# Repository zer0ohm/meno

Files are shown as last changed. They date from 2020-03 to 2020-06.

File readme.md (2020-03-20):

# meno
試作中のArduino互換機 (無保証)

## Meno
マイコンにATmega2560、USBコネクタにType-Cを採用したボードです。 GPIOは公式のMEGAと同じ70本です。(内訳: ディジタルI/O 54本、アナログI/O 16本)
* 回路図: [Meno_sch.pdf](https://github.com/zer0ohm/meno/blob/master/Meno/Schematic/Meno_sch.pdf)
* 部品表: [Meno_BOM.pdf](https://github.com/zer0ohm/meno/blob/master/Meno/Docs/Meno_BOM.pdf) もしくは [Meno_BOM.md](https://github.com/zer0ohm/meno/blob/master/Meno/Docs/Meno_BOM.md)
* 組み立て方法: [Meno_assemble.md](https://github.com/zer0ohm/meno/blob/master/Meno/Docs/Meno_assemble.md)

<!--// まだ構想中なのでとりあえずコメントアウト
## Meno F4
MenoのマイコンをSTM32F4(STM32F446RET)にアップグレードしたボードです。USBコネクタは引き続きType-Cを採用しています。
* 回路図: [MenoF4_RevPrototype_sch.pdf](https://github.com/zer0ohm/meno/blob/master/MenoF4/Schematic/MenoF4_RevPrototype_sch.pdf)
* 部品表: [MenoF4_BOM.pdf](https://github.com/zer0ohm/meno/blob/master/MenoF4/Docs/MenoF4_BOM.pdf) もしくは [MenoF4_BOM.md](https://github.com/zer0ohm/meno/blob/master/MenoF4/Docs/MenoF4_BOM.md)
* 組み立て方法: [MenoF4_assemble.md](https://github.com/zer0ohm/meno/blob/master/MenoF4/Docs/Meno_assemble.md)
-->

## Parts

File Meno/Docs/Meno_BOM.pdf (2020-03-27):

基板上部品番号 | 個数 | 製品名や各種定数 | 製品型番 | 製造社名 | 部品概要
C1, 2, 3, 4, 5, 8, 9, 11, 14 | 9 | 0.1u | GRM219F11H104ZA01D | Murata Electronics | チップコンデンサ (*1)
C6, 7 | 2 | 22p | GRM21A5C2D220JW01D | Murata Electronics | チップコンデンサ
C10 | 1 | 0.22u | GCM21BR71H224KA37K | Murata Electronics | チップコンデンサ
C12, 13, 15 | 3 | 1u | GRM21BC72A105KE01 | Murata Electronics | チップコンデンサ
D1 | 1 | L | PG1112H-TR (*2) | STANLEY ELECTRIC | Lチカ用LED
D2 | 1 | TX | PG1112H-TR (*2) | STANLEY ELECTRIC | シリアル通信時インジケータ用LED
D3 | 1 | RX | PG1112H-TR (*2) | STANLEY ELECTRIC | シリアル通信時インジケータ用LED
D4 | 1 | ON | PG1112H-TR (*2) | STANLEY ELECTRIC | 電源投入インジケータ用LED
D5 | 1 | 1N4148W | 1N4148W-7-F | Diodes Incorporated | 汎用ダイオード
D6, 7 | 2 | RB160MM-30 | RB160MM-30TR | Rohm Semiconductor | ショットキーダイオード
F1 | 1 | MF-MSMF050-2 | MF-MSMF050-2 | Bourns | リセッタブルヒューズ (Ih=500[mA], It=1[A])
J1 | 1 | 5077CR-16SMC2 | 5077CR-16SMC2-BK-TR | Neltron Industrial | USB3.1 Type-C型コネクタ
J2 | 1 | AVR-ISP-6 | PH-2x7SG | Useconn Electronics | AVR ICSP用ピンヘッダ
J3 | 1 | 18742 | 18742 | 4UCON | DCジャック (20[V], 4[A]絶対定格)
J4, 5, 6 | 3 | Conn_01x08, 10, 19 | FHU-1x42SG | Useconn Electronics | GPIO用ピンソケット (*3)
J7, 8, 9 | 3 | Conn_01x06, 08, 15 | FHU-1x42SG | Useconn Electronics | GPIO用ピンソケット (*3)
J10 | 1 | Conn_02x12 | FHU-2x42SG | Useconn Electronics | GPIO用ピンソケット
L1 | 1 | MH2029-300Y | MH2029-300Y | Bourns | フェライトビーズ
Q1 | 1 | IRLML6402 | IRLML6402TRPBF | International Rectifier | Pch型MOSFET
R1, 2, 3 | 3 | 10k | RK73B2ATTD103J | KOA | チップ抵抗 (0.25W)
R4, 5, 6, 7 | 4 | 1k | RK73B2ATTD102J | KOA | チップ抵抗 (0.25W)
R8, 9 | 2 | 5.1k | RK73B2ATTD512J | KOA | チップ抵抗 (0.25W)
R10 | 1 | 33k | RK73B2ATTD333J | KOA | チップ抵抗 (0.25W)
SW1 | 1 | B3FS-1050P | B3FS-1050P | Omron Electronics | タクトスイッチ
U1 | 1 | ATmega2560-16AUR | ATmega2560-16AUR | Atmel/Microchip | マイコン
U2 | 1 | FT232RL | FT232RL-REEL | FTDI | USB/シリアル変換IC
U3 | 1 | LM340MPX-5.0/NOPB | LM340MPX-5.0/NOPB | Texas Instruments | 5Vレギュレータ (1.5[A]絶対定格)
U4 | 1 | TLV75733PDBVR | TLV75733PDBVR | Texas Instruments | 3.3Vレギュレータ (1.0[A]絶対定格)
Y1 | 1 | FA238-16MHz | FA-238 16.0000MB-K3 | EPSON | 水晶振動子

*3: ピンソケットの外側のピン配置はArduino Unoと互換。 Meno-PinMapping.pngを参照。

*2: ロットによってはOpto Supply製のOSG80805C1Cの場合あり。 もしくは同等品 (参考: 条件= IF=20[mA](typ), VF=2.1[V](typ), 2012Metric)。

*1: 既にディスコン(製造中止)しているため、次回以降の生産時は同社製の代替品に切替予定 (参考: 条件=0.1uF, 50V, X7R, 2012Metric)。

Meno BOM v1.0-20200327 1頁目/3頁

Meno BOM v1.0-20200327 2頁目/3頁

基板上部品番号 | 個数 | フットプリント - 特記なしはKiCadでの名称 | Digikey通販コード | 秋月通販コード
C1, 2, 3, 4, 5, 8, 9, 11, 14 | 9 | Capacitor_SMD:C_0805_2012Metric_Pad1.15x1.40mm_HandSolder N/A | | P-13372 (50個/袋)
C6, 7 | 2 | Capacitor_SMD:C_0805_2012Metric_Pad1.15x1.41mm_HandSolder 490-14650-1-ND | | N/A
C10 | 1 | Capacitor_SMD:C_0805_2012Metric_Pad1.15x1.42mm_HandSolder 490-13311-1-ND | | N/A
C12, 13, 15 | 3 | Capacitor_SMD:C_0805_2012Metric_Pad1.15x1.43mm_HandSolder 490-14464-1-ND | | P-13699 (10個/袋)
D1 | 1 | LED_SMD:LED_0805_2012Metric_Pad1.15x1.40mm_HandSolder | 404-1021-1-ND | I-09340 (20個/袋)
D2 | 1 | LED_SMD:LED_0805_2012Metric_Pad1.15x1.41mm_HandSolder | D1に同じ | D1に同じ
D3 | 1 | LED_SMD:LED_0805_2012Metric_Pad1.15x1.42mm_HandSolder | D1に同じ | D1に同じ
D4 | 1 | LED_SMD:LED_0805_2012Metric_Pad1.15x1.43mm_HandSolder | D1に同じ | D1に同じ
D5 | 1 | SOD123(F)-HandSolder:D_SOD-123 | 1N4148W-FDICT-ND | I-07084 (40個/袋)
D6, 7 | 2 | SOD123(F)-HandSolder:D_SOD-123 | RB160MM-30CT-ND | I-01398 (10個/袋)
F1 | 1 | Fuse:Fuse_1812_4532Metric_Pad1.30x3.40mm_HandSolder | MF-MSMF050-2CT-ND | N/A
J1 | 1 | 5077CR-16SMC2-BK-TR:GCT_USB4105-GF-A (gct.coから) | 2073-USB4105-GF-ACT-ND | C-14356
J2 | 1 | Connector_PinHeader_2.54mm:PinHeader_2x03_P2.54mm_Vertical N/A | | C-00166
J3 | 1 | CUI_PJ-102A:CUI_PJ-102A (cuidevices.comから) | CP-102A-ND | C-09408
J4, 5, 6 | 3 | Connector_PinSocket_2.54mm:PinSocket_1x08, 10, 19 | N/A | C-05779
J7, 8, 9 | 3 | Connector_PinSocket_2.54mm:PinSocket_1x06, 08, 15 | J4, 5, 6に同じ | J4, 5, 6に同じ
J10 | 1 | Connector_PinSocket_2.54mm:PinSocket_2x12 | J4, 5, 6に同じ | C-05780
L1 | 1 | Inductor_SMD:L_0805_2012Metric_Pad1.15x1.40mm_HandSolder | MH2029-300YCT-ND | N/A
Q1 | 1 | Package_TO_SOT_SMD:SOT-23_Handsoldering | IRLML6402PBFCT-ND | I-02553 (10個/袋)
R1, 2, 3 | 3 | Resistor_SMD:R_0805_2012Metric_Pad1.15x1.40mm_HandSolder | 2019-RK73B2ATTD102JCT-ND | N/A
R4, 5, 6, 7 | 4 | Resistor_SMD:R_0805_2012Metric_Pad1.15x1.41mm_HandSolder | 2019-RK73B2ATTD103JCT-ND | N/A
R8, 9 | 2 | Resistor_SMD:R_0805_2012Metric_Pad1.15x1.42mm_HandSolder | 2019-RK73B2ATTD512JCT-ND | N/A
R10 | 1 | Resistor_SMD:R_0805_2012Metric_Pad1.15x1.43mm_HandSolder | 2019-RK73B2ATTD333JCT-ND | N/A
SW1 | 1 | B3FS-1050P:B3FS-1012 (ultralibrarian.comから) | Z5350CT-ND | P-10527
U1 | 1 | Package_QFP:TQFP-100_14x14mm_P0.5mm | ATMEGA2560-16AURCT-ND | N/A
U2 | 1 | Package_SO:SSOP-28_5.3x10.2mm_P0.65mm | 768-1007-1-ND | I-01739
U3 | 1 | Package_TO_SOT_SMD:SOT-223-3_TabPin2 | LM340MPX-5.0/NOPBCT-ND | N/A
U4 | 1 | Package_TO_SOT_SMD:SOT-23-5_HandSoldering | 296-50414-1-ND | N/A
Y1 | 1 | Crystal:Crystal_SMD_SeikoEpson_FA238-4Pin_3.2x2.5mm_HandSoldering | SER4046CT-ND | P-02457 (4個/袋)

基板上部品番号 | 個数 | データシート - もしくは関連資料
C1, 2, 3, 4, 5, 8, 9, 11, 14 | 9 | http://akizukidenshi.com/download/ds/murata/grm219f11h104za01.pdf
C6, 7 | 2 | https://psearch.jp.murata.com/capacitor/product/GRM21A5C2D220JW01%23.html
C10 | 1 | https://psearch.jp.murata.com/capacitor/product/GCM21BR71H224KA37%23.html
C12, 13, 15 | 3 | https://psearch.jp.murata.com/capacitor/product/GRM21BC72A105KE01%23.html
D1 | 1 | https://media.digikey.com/pdf/Data%20Sheets/Stanley%20Electric%20PDFs/BR1112H.pdf
D2 | 1
D3 | 1
D4 | 1
D5 | 1 | https://www.diodes.com/assets/Datasheets/ds30086.pdf
D6, 7 | 2 | https://fscdn.rohm.com/jp/products/databook/datasheet/discrete/diode/schottky_barrier/rb160mm-30tr-j.pdf
F1 | 1 | https://www.bourns.com/docs/Product-Datasheets/mfmsmf.pdf
J1 | 1 | https://www.amphenol-icc.com/media/wysiwyg/files/drawing/12401610e4x2a.pdf
J2 | 1 | http://akizukidenshi.com/download/ds/useconn/PH-2xXXSG-AD.pdf
J3 | 1 | https://www.cuidevices.com/product/resource/pj-102a.pdf
J4, 5, 6 | 3
J7, 8, 9 | 3
J10 | 1 | http://akizukidenshi.com/download/ds/useconn/FHU-2xXXSG-AD.pdf
L1 | 1 | https://www.bourns.com/docs/Product-Datasheets/mh.pdf
Q1 | 1 | https://www.infineon.com/dgdl/irlml6402pbf.pdf?fileId=5546d462533600a401535668d5c2263c
R1, 2, 3 | 3 | https://www.koaglobal.com/-/media/Files/KOA_Global/product/commonpdf/rk73b.pdf
R4, 5, 6, 7 | 4
R8, 9 | 2
R10 | 1
SW1 | 1 | https://omronfs.omron.com/ja_JP/ecb/products/pdf/b3fs.pdf
U1 | 1 | https://ww1.microchip.com/downloads/en/DeviceDoc/Atmel-2549-8-bit-AVR-Microcontroller-ATmega640-1280-1281-2560-2561_datasheet.pdf (https://ww1.microchip.com/downloads/en/DeviceDoc/Atmel-2549-8-bit-AVR-Microcontroller-ATmega640-1280-1281-2560-2561_datasheet.pdf)
U2 | 1 | https://www.ftdichip.com/Products/ICs/FT232RL.htm
U3 | 1 | https://www.ti.com/lit/ds/symlink/lm340.pdf
U4 | 1 | https://www.ti.com/lit/ds/symlink/tlv757p.pdf
Y1 | 1 | https://support.epson.biz/td/api/doc_check.php?dl=brief_FA-238&lang=ja

Meno BOM v1.0-20200327 3頁目/3頁

http://akizukidenshi.com/download/ds/useconn/FHU-1.pdf

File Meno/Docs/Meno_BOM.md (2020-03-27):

# Meno BOM v1.0-20200327
 * 印刷用データはMeno_BOM.pdfをご利用ください。

## 1ページ目 (部品名や概要等)

| 基板上部品番号 | 個数 | 製品名や各種定数  | 製品型番 | 製造社名 | 部品概要 |
|---|---|---|---|---|---|
| C1, 2, 3, 4, 5, 8, 9, 11, 14 | 9 | 0.1u | GRM219F11H104ZA01D  | Murata Electronics | チップコンデンサ (*1) |
| C6, 7 | 2 | 22p | GRM21A5C2D220JW01D  | Murata Electronics | チップコンデンサ |
| C10 | 1 | 0.22u | GCM21BR71H224KA37K  | Murata Electronics | チップコンデンサ |
| C12, 13, 15 | 3 | 1u | GRM21BC72A105KE01 | Murata Electronics | チップコンデンサ |
| D1 | 1 | L | PG1112H-TR (*2) | STANLEY ELECTRIC | Lチカ用LED |
| D2 | 1 | TX | PG1112H-TR (*2) | STANLEY ELECTRIC | シリアル通信時インジケータ用LED |
| D3 | 1 | RX | PG1112H-TR (*2) | STANLEY ELECTRIC | シリアル通信時インジケータ用LED |
| D4 | 1 | ON | PG1112H-TR (*2) | STANLEY ELECTRIC | 電源投入インジケータ用LED |
| D5 | 1 | 1N4148W | 1N4148W-7-F | Diodes Incorporated | 汎用ダイオード |
| D6, 7 | 2 | RB160MM-30 | RB160MM-30TR | Rohm Semiconductor | ショットキーダイオード |
| F1 | 1 | MF-MSMF050-2 | MF-MSMF050-2 | Bourns | リセッタブルヒューズ (Ih=500[mA], It=1[A]) |
| J1 | 1 | 5077CR-16SMC2 | 5077CR-16SMC2-BK-TR | Neltron Industrial | USB3.1 Type-C型コネクタ |
| J2 | 1 | AVR-ISP-6 | PH-2x7SG | Useconn Electronics | AVR ICSP用ピンヘッダ |
| J3 | 1 | 18742 | 18742 | 4UCON | DCジャック (20[V], 4[A]絶対定格) |
| J4, 5, 6 | 3 | Conn_01x08, 10, 19 | FHU-1x42SG | Useconn Electronics | GPIO用ピンソケット (*3) |
| J7, 8, 9 | 3 | Conn_01x06, 08, 15 | FHU-1x42SG | Useconn Electronics | GPIO用ピンソケット (*3) |
| J10 | 1 | Conn_02x12 | FHU-2x42SG | Useconn Electronics | GPIO用ピンソケット |
| L1 | 1 | MH2029-300Y | MH2029-300Y | Bourns | フェライトビーズ |
| Q1 | 1 | IRLML6402 | IRLML6402TRPBF | International Rectifier | Pch型MOSFET |
| R1, 2, 3 | 3 | 10k | RK73B2ATTD103J | KOA | チップ抵抗 (0.25W) |
| R4, 5, 6, 7 | 4 | 1k | RK73B2ATTD102J | KOA | チップ抵抗 (0.25W) |
| R8, 9 | 2 | 5.1k | RK73B2ATTD512J | KOA | チップ抵抗 (0.25W) |
| R10 | 1 | 33k | RK73B2ATTD333J | KOA | チップ抵抗 (0.25W) |
| SW1 | 1 | B3FS-1050P | B3FS-1050P | Omron Electronics | タクトスイッチ |
| U1 | 1 | ATmega2560-16AUR  | ATmega2560-16AUR | Atmel/Microchip | マイコン |
| U2 | 1 | FT232RL | FT232RL-REEL | FTDI | USB/シリアル変換IC |
| U3 | 1 | LM340MPX-5.0/NOPB | LM340MPX-5.0/NOPB | Texas Instruments | 5Vレギュレータ (1.5[A]絶対定格) |
| U4 | 1 | TLV75733PDBVR | TLV75733PDBVR | Texas Instruments | 3.3Vレギュレータ (1.0[A]絶対定格) |
| Y1 | 1 | FA238-16MHz | FA-238 16.0000MB-K3 | EPSON | 水晶振動子 |

### 注釈
 * &#x2a;1: 既にディスコン(製造中止)しているため、次回以降の生産時は同社製の代替品に切替予定 (参考: 条件=0.1uF, 50V, X7R, 2012Metric)。
 * &#x2a;2: ロットによってはOpto Supply製のOSG80805C1Cの場合あり。 もしくは同等品 (参考: 条件= IF=20[mA]&#x28;typ&#x29;, VF=2.1[V]&#x28;typ&#x29;, 2012Metric)。
 * &#x2a;3: ピンソケットの外側のピン配置はArduino Unoと互換。 Meno-PinMapping.pngを参照。

## 2ページ目 (フットプリントや通販コード)

| 基板上部品番号 | 個数 | フットプリント - 特記なしはKiCadでの名称 | Digikey通販コード | 秋月通販コード |
|---|---|---|---|---|
| C1, 2, 3, 4, 5, 8, 9, 11, 14 | 9 | Capacitor_SMD:C_0805_2012Metric_Pad1.15x1.41mm_HandSolder | N/A | P-13372 (50個/袋) |
| C6, 7 | 2 | Capacitor_SMD:C_0805_2012Metric_Pad1.15x1.41mm_HandSolder | 490-14650-1-ND | N/A |
| C10 | 1 | Capacitor_SMD:C_0805_2012Metric_Pad1.15x1.41mm_HandSolder | 490-13311-1-ND | N/A |
| C12, 13, 15 | 3 | Capacitor_SMD:C_0805_2012Metric_Pad1.15x1.41mm_HandSolder | 490-14464-1-ND | P-13699 (10個/袋) |
| D1 | 1 | LED_SMD:LED_0805_2012Metric_Pad1.15x1.40mm_HandSolder | 404-1021-1-ND | I-09340 (20個/袋) |
| D2 | 1 | LED_SMD:LED_0805_2012Metric_Pad1.15x1.40mm_HandSolder | D1に同じ | D1に同じ |
| D3 | 1 | LED_SMD:LED_0805_2012Metric_Pad1.15x1.40mm_HandSolder | D1に同じ | D1に同じ |
| D4 | 1 | LED_SMD:LED_0805_2012Metric_Pad1.15x1.40mm_HandSolder | D1に同じ | D1に同じ |
| D5 | 1 | SOD123(F)-HandSolder:D_SOD-123 | 1N4148W-FDICT-ND | I-07084 (40個/袋) |
| D6, 7 | 2 | SOD123(F)-HandSolder:D_SOD-123 | RB160MM-30CT-ND | I-01398 (10個/袋) |
| F1 | 1 | Fuse:Fuse_1812_4532Metric_Pad1.30x3.40mm_HandSolder | MF-MSMF050-2CT-ND | N/A |
| J1 | 1 | 5077CR-16SMC2-BK-TR:GCT_USB4105-GF-A (gct.coから) | 2073-USB4105-GF-ACT-ND | C-14356 |
| J2 | 1 | Connector_PinHeader_2.54mm:PinHeader_2x03_P2.54mm_Vertical | N/A | C-00166 |
| J3 | 1 | CUI_PJ-102A:CUI_PJ-102A (cuidevices.comから) | CP-102AH-ND | C-09408 |
| J4, 5, 6 | 3 | Connector_PinSocket_2.54mm:PinSocket_1x08, 10, 19 | N/A | C-05779 |
| J7, 8, 9 | 3 | Connector_PinSocket_2.54mm:PinSocket_1x06, 08, 15 | J4, 5, 6に同じ | J4, 5, 6に同じ |
| J10 | 1 | Connector_PinSocket_2.54mm:PinSocket_2x12 | J4, 5, 6に同じ | C-05780 |
| L1 | 1 | Inductor_SMD:L_0805_2012Metric_Pad1.15x1.40mm_HandSolder | MH2029-300YCT-ND | N/A |
| Q1 | 1 | Package_TO_SOT_SMD:SOT-23_Handsoldering | IRLML6402PBFCT-ND | I-02553 (10個/袋) |
| R1, 2, 3 | 3 | Resistor_SMD:R_0805_2012Metric_Pad1.15x1.41mm_HandSolder | 2019-RK73B2ATTD102JCT-ND | N/A |
| R4, 5, 6, 7 | 4 | Resistor_SMD:R_0805_2012Metric_Pad1.15x1.41mm_HandSolder | 2019-RK73B2ATTD103JCT-ND | N/A |
| R8, 9 | 2 | Resistor_SMD:R_0805_2012Metric_Pad1.15x1.41mm_HandSolder | 2019-RK73B2ATTD512JCT-ND | N/A |
| R10 | 1 | Resistor_SMD:R_0805_2012Metric_Pad1.15x1.41mm_HandSolder | 2019-RK73B2ATTD333JCT-ND | N/A |
| SW1 | 1 | B3FS-1050P:B3FS-1012 (ultralibrarian.comから) | Z5350CT-ND | P-10527 |
| U1 | 1 | Package_QFP:TQFP-100_14x14mm_P0.5mm | ATMEGA2560-16AURCT-ND | N/A |
| U2 | 1 | Package_SO:SSOP-28_5.3x10.2mm_P0.65mm | 768-1007-1-ND | I-01739 |
| U3 | 1 | Package_TO_SOT_SMD:SOT-223-3_TabPin2 | LM340MPX-5.0/NOPBCT-ND | N/A |
| U4 | 1 | Package_TO_SOT_SMD:SOT-23-5_HandSoldering | 296-50414-1-ND | N/A |
| Y1 | 1 | Crystal:Crystal_SMD_SeikoEpson_FA238-4Pin_3.2x2.5mm_HandSoldering | SER4046CT-ND | P-02457 (4個/袋)  |

## 3ページ目 (データシートや関連資料)

| 基板上部品番号 | 個数 | データシート - もしくは関連資料 |
|---|---|---|
| C1, 2, 3, 4, 5, 8, 9, 11, 14 | 9 | http://akizukidenshi.com/download/ds/murata/grm219f11h104za01.pdf |
| C6, 7 | 2 | https://psearch.jp.murata.com/capacitor/product/GRM21A5C2D220JW01%23.html |
| C10 | 1 | https://psearch.jp.murata.com/capacitor/product/GCM21BR71H224KA37%23.html |
| C12, 13, 15 | 3 | https://psearch.jp.murata.com/capacitor/product/GRM21BC72A105KE01%23.html |
| D1 | 1 | https://media.digikey.com/pdf/Data%20Sheets/Stanley%20Electric%20PDFs/BR1112H.pdf |
| D2 | 1 | https://media.digikey.com/pdf/Data%20Sheets/Stanley%20Electric%20PDFs/BR1112H.pdf |
| D3 | 1 | https://media.digikey.com/pdf/Data%20Sheets/Stanley%20Electric%20PDFs/BR1112H.pdf |
| D4 | 1 | https://media.digikey.com/pdf/Data%20Sheets/Stanley%20Electric%20PDFs/BR1112H.pdf |
| D5 | 1 | https://www.diodes.com/assets/Datasheets/ds30086.pdf |
| D6, 7 | 2 | https://fscdn.rohm.com/jp/products/databook/datasheet/discrete/diode/schottky_barrier/rb160mm-30tr-j.pdf |
| F1 | 1 | https://www.bourns.com/docs/Product-Datasheets/mfmsmf.pdf |
| J1 | 1 | https://www.amphenol-icc.com/media/wysiwyg/files/drawing/12401610e4x2a.pdf |
| J2 | 1 | http://akizukidenshi.com/download/ds/useconn/PH-2xXXSG-AD.pdf |
| J3 | 1 | https://www.cuidevices.com/product/resource/pj-102a.pdf |
| J4, 5, 6 | 1 | http://akizukidenshi.com/download/ds/useconn/FHU-1.pdf |
| J7, 8, 9 | 1 | http://akizukidenshi.com/download/ds/useconn/FHU-1.pdf |
| J10 | 1 | http://akizukidenshi.com/download/ds/useconn/FHU-2xXXSG-AD.pdf |
| L1 | 1 | https://www.bourns.com/docs/Product-Datasheets/mh.pdf |
| Q1 | 1 | https://www.infineon.com/dgdl/irlml6402pbf.pdf?fileId=5546d462533600a401535668d5c2263c |
| R1, 2, 3 | 3 | https://www.koaglobal.com/-/media/Files/KOA_Global/product/commonpdf/rk73b.pdf |
| R4, 5, 6, 7 | 4 | https://www.koaglobal.com/-/media/Files/KOA_Global/product/commonpdf/rk73b.pdf |
| R8, 9 | 2 | https://www.koaglobal.com/-/media/Files/KOA_Global/product/commonpdf/rk73b.pdf |
| R10 | 1 | https://www.koaglobal.com/-/media/Files/KOA_Global/product/commonpdf/rk73b.pdf |
| SW1 | 1 | https://omronfs.omron.com/ja_JP/ecb/products/pdf/b3fs.pdf |
| U1 | 1 | https://ww1.microchip.com/downloads/en/DeviceDoc/Atmel-2549-8-bit-AVR-Microcontroller-ATmega640-1280-1281-2560-2561_datasheet.pdf |
| U2 | 1 | https://www.ftdichip.com/Products/ICs/FT232RL.htm |
| U3 | 1 | https://www.ti.com/lit/ds/symlink/lm340.pdf |
| U4 | 1 | https://www.ti.com/lit/ds/symlink/tlv757p.pdf |
| Y1 | 1 | https://support.epson.biz/td/api/doc_check.php?dl=brief_FA-238&lang=ja |

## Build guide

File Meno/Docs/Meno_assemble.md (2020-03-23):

# Menoの組み立てからブートローダの書き込みまで
## 必要なもの
* 部品
* ハンダごてorヒートガン (もしくは両方) ※1
* Arduino Uno (互換機でも可)
* USBケーブル - 2本 (Uno用のType-BケーブルとMeno用のType-Cケーブル)
* ジャンパ線 - 6本 (オスオスのもの)
* 多少の電子工作知識とハンダ付けの腕
* ~あきらめない気持ち (重要)~

※1: 参考としてHAKKO製ヒーティングガン FV-310-81の例では```風量調節ツマミは1(0.15m^3/min) or 2(0.17m^3/min)で、温度調節ツマミが3(245℃ or 230℃)```になるよう調節するとヒートガンでもハンダ付けが行えると思われます。

## 部品を入手する
* まず部品を[部品表](https://github.com/zer0ohm/meno/tree/master/Meno/Docs/Meno_BOM.pdf)に従って入手していきます。(※今回は秋月電子通商とDigikeyで入手しましたが、その他の店舗で入手できる場合はそちらでも構いません。)

## ハンダ付け
* 1.で入手した部品を、先程の[部品表](https://github.com/zer0ohm/meno/tree/master/Meno/Docs/Meno_BOM.pdf)と基板上の部品番号(例: ATmega2560 → U1)に従ってハンダ付けを行います。

### チップ抵抗(R1～R10)・コンデンサ(C1～C15)、フェライトビーズ(L1)、ヒューズ(F1)
* いずれも極性(※1)はありません。しかし抵抗には抵抗値を表す3桁の数字が書かれており、真上から見て読みやすい方向に実装することをおすすめします。
  * ※1: 今回使用するコンデンサは全てセラミックコンデンサですが、コンデンサの種類によっては極性がありますのでよく確認してから実装して下さい。

### ダイオード・LED(D1～7)
* ダイオードの端に縦線、もしくは緑色の目印がある端子側がカソードになっています。また基板上にはアノード側に「+」のシルクを設置しています。目印とシルクを合わせ正しい向きになるよう実装して下さい。(図1参照)
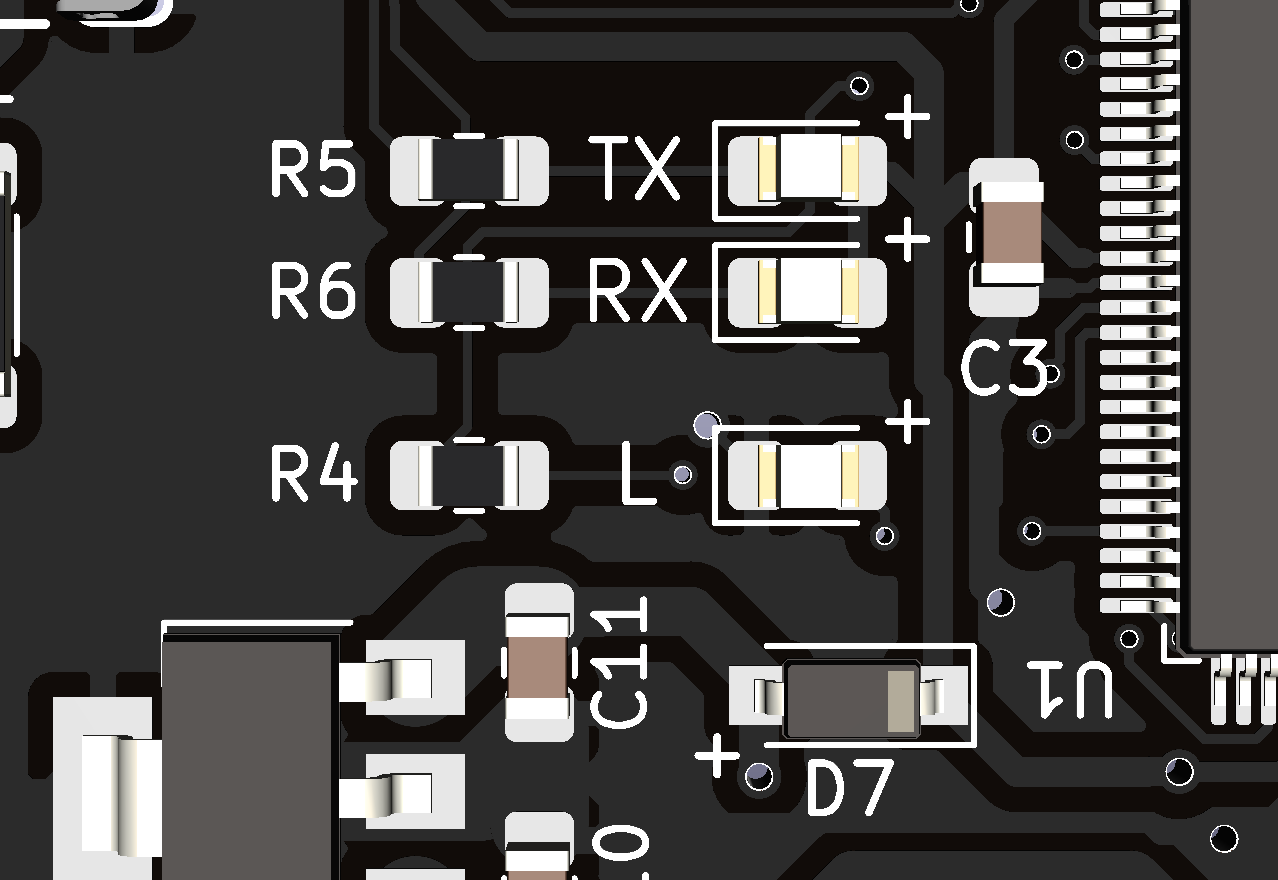
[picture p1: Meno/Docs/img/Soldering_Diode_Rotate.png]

図1: ダイオードのアノードを示す目印("+"側がアノード)

### USBコネクタ(J1)
 * 部品の構造上、手ハンダが難しい可能性があります。その場合は予めランドにペーストハンダを塗っておき、その上に部品を置いてからヒートガンで実装する方法があります。(図2参照)
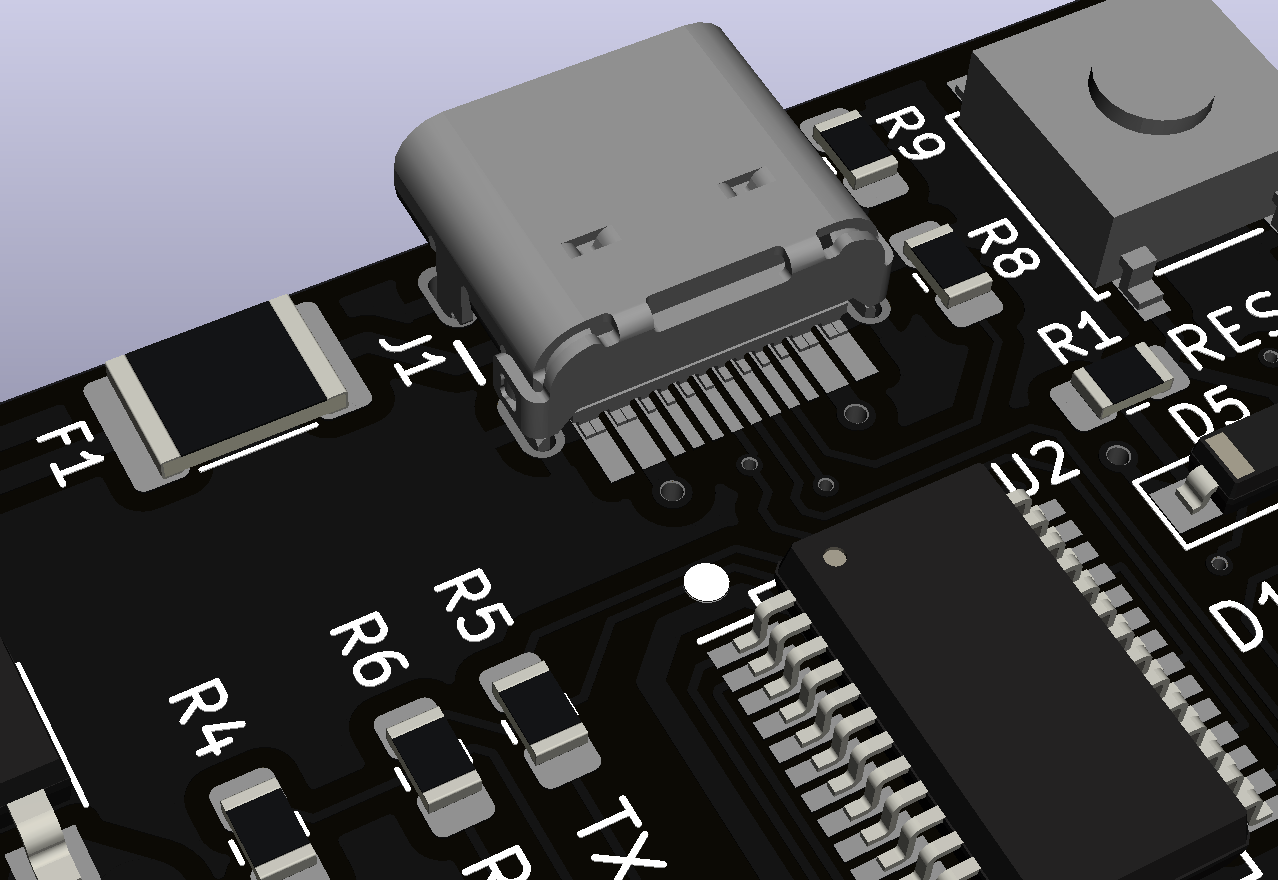
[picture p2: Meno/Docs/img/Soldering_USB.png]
 
 図2: USBコネクタの端子

### IC(U1~4)
* U3の三端子レギュレータのような正しい向きでないと物理的に実装できないものを除き、ICの1番端子付近に白丸のシルクを設置しています。IC側の目印(丸や切り欠き)とシルクを合わせ正しい向きになるよう実装して下さい。(図3参照)
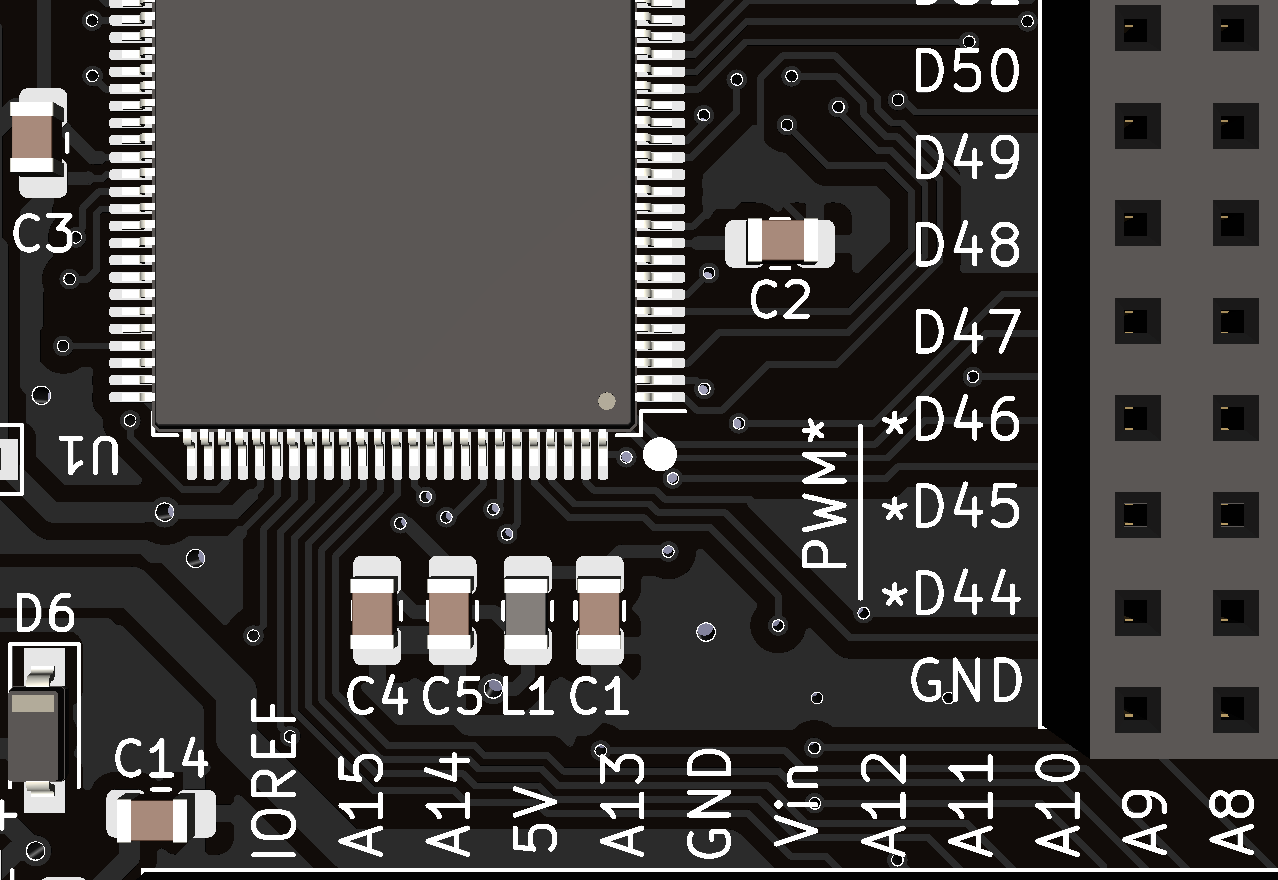
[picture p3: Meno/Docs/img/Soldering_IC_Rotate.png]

図3: ICの向きを示す目印(IC側の小さな丸とシルク側の白丸を合わせる)

### 水晶振動子(Y1)
* 水晶振動子は数字が逆にならない用に実装して下さい。(図4参照)
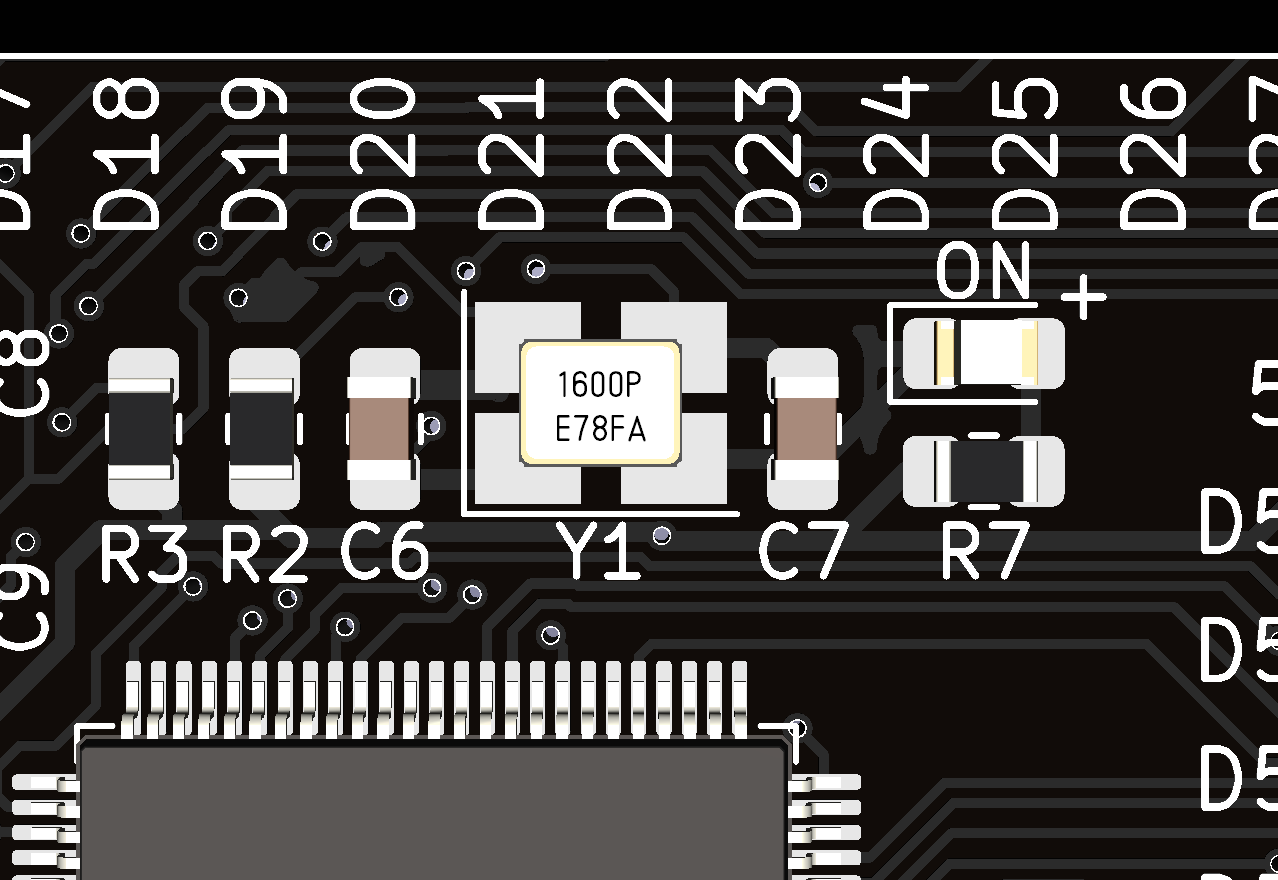
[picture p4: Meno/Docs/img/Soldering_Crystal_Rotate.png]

図4: 水晶振動子の設置方向(白丸が4番目の端子)

### ピンソケット・ヘッダ(基板上に部品番号記載なし)
* ピンソケットやピンヘッダは分割型になっています。それぞれ2x19(リセットスイッチ側のソケット)、2x15(DCジャック側のソケット)、2x12(ICSPの隣)、2x3(シルクで「ICSP」と書いてあるところ)となるように手やニッパーなどで分割して下さい。(図5参照)
 * なおピンソケットの場合はメス側(ジャンパ線を刺す方)を上に、ピンヘッダの場合はオスの長い方(黒いプラスチックが表側に来るように)を上にして下さい。

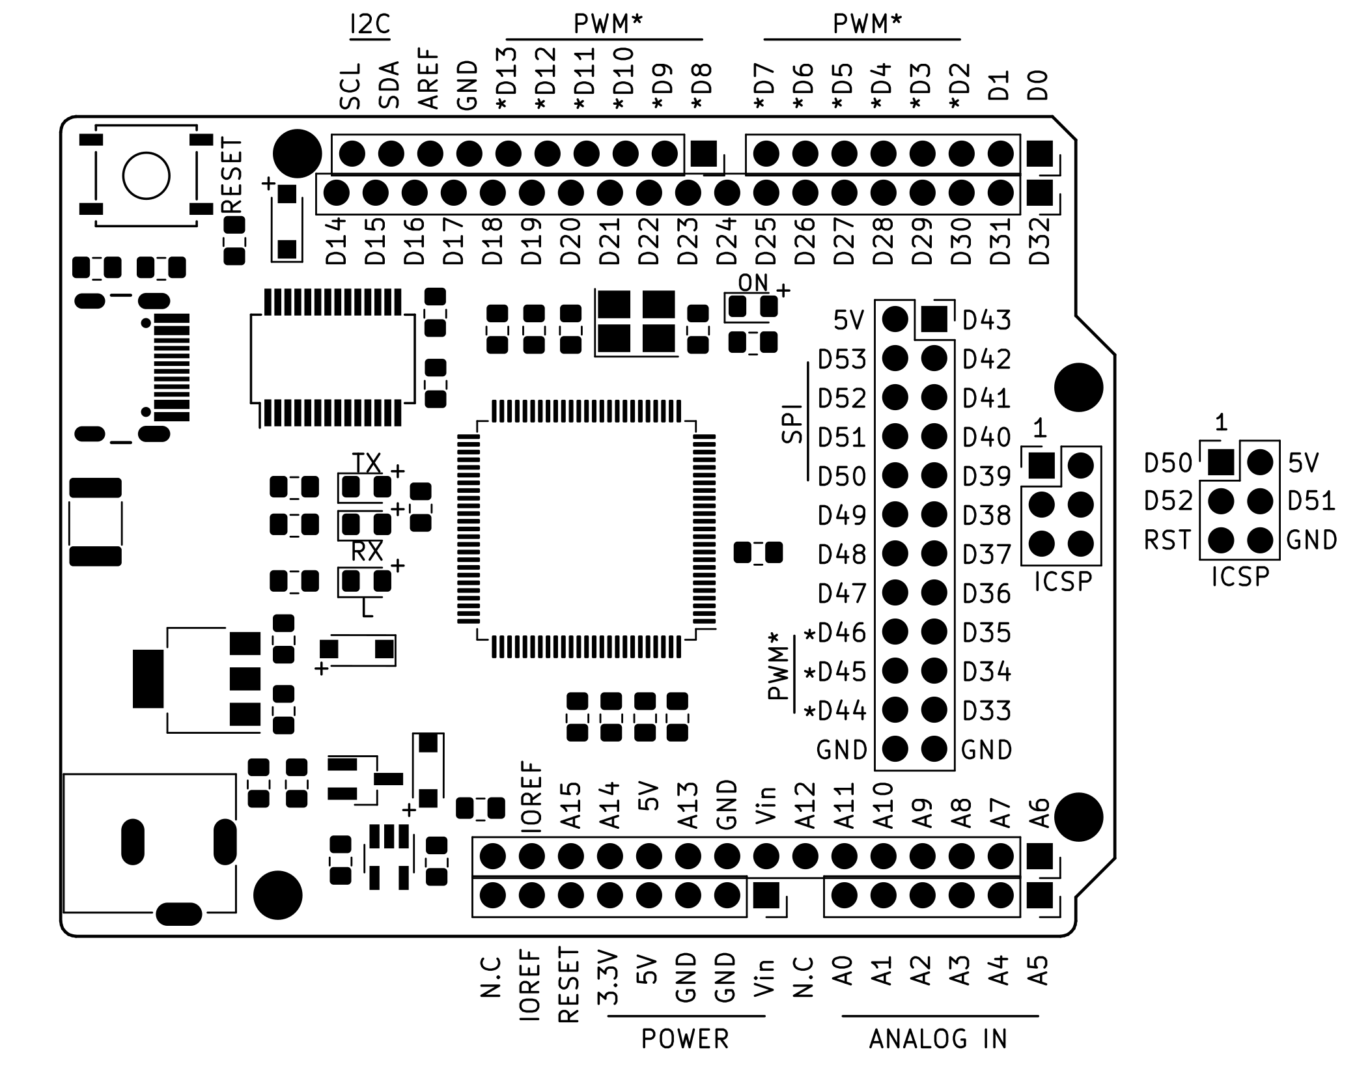
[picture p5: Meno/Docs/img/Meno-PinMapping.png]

図5: [参考]Menoのピン配置図

### ハンダ付けが終わった基板
* 一通りハンダ付けが終わった基板を次に示します。
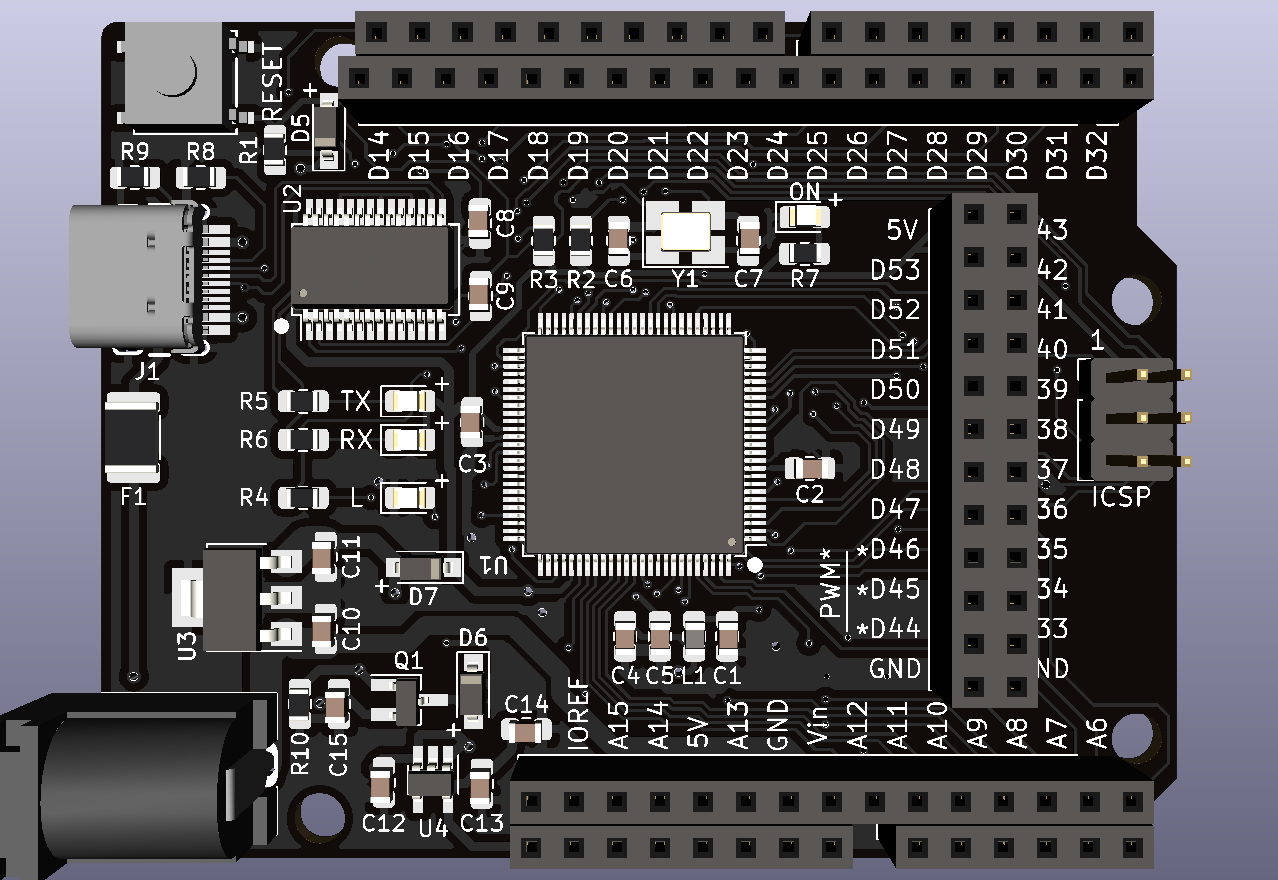
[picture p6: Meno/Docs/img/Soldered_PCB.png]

図6: ハンダ付けした基板

## ブートローダを書き込む
* まず用意したArduino Uno(以下、プログラマ)にArduinoISPのスケッチを書き込みます。
  * 場所は ```ファイル>スケッチ例>11.ArduinoISP>ArduinoISP```です。
* 次にプログラマとMeno(以下、ターゲット)を表やピン配置図(図5参照)の通りにジャンパ線で配線します。

|プログラマ  |ターゲット |
|---|---|
|5V |5V |
|GND |GND |
|D10 |RESET |
|D11 |D51 |
|D12 |D50 |
|D13 |D52 |

表1 プログラマ/ターゲットのピン変換表

* ボードやシリアルポートを指定します

|設定名 |値 |
|---|---|
|ボード |Arduino Mega or Mega 2560 |
|プロセッサ |ATmega2560 (Mega 2560) |
|シリアルポート|プログラマが接続されているシリアルポート (例:COM4) |
|書込装置 |Arduino as ISP |

表2 ターゲットの設定

* 「ブートローダを書き込む」をクリックします

* ブートローダの書き込みに成功すると実装したLED(「L」と書かれたLED)が1秒毎に点灯します。あとは他のArduinoボードと同じ様にコンパイルと書き込みでスケッチを書き込むことができるようになります。その際は次の通りに設定してから書き込みを行って下さい。

|設定名 |値 |
|---|---|
|ボード |Arduino Mega or Mega 2560 |
|プロセッサ |ATmega2560 (Mega 2560) |
|シリアルポート|ターゲットが接続されているシリアルポート (例:COM4)|

表3 オリジナルのスケッチを書き込む時の設定

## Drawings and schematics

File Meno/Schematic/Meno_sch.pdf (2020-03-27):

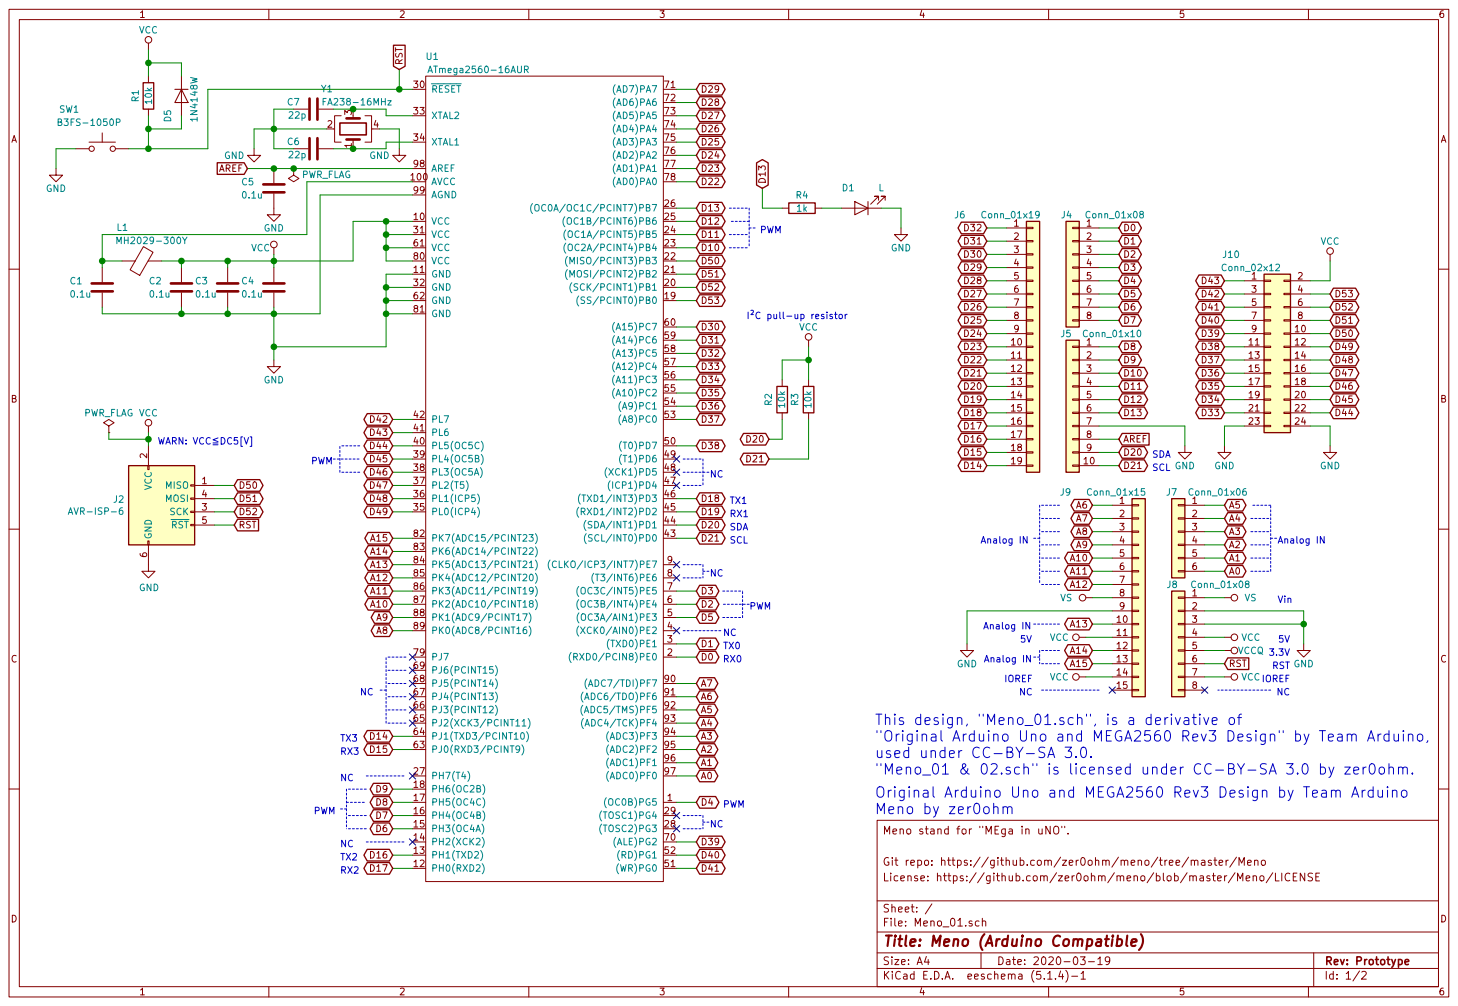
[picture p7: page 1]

I²C pull-up resistor PWM

2 SCK 3 MOSI 4 RST 5 GND

RST Original Arduino Uno and MEGA2560 Rev3 Design by Team Arduino

This design, "Meno_01.sch", is a derivative of
"Original Arduino Uno and MEGA2560 Rev3 Design" by Team Arduino,
used under CC-BY-SA 3.0.
"Meno_01 & 02.sch" is licensed under CC-BY-SA 3.0 by zer0ohm.

Meno by zer0ohm
Meno stand for "MEga in uNO".

Git repo: https://github.com/zer0ohm/meno/tree/master/Meno
File: Meno_01.sch Sheet: / License: https://github.com/zer0ohm/meno/blob/master/Meno/LICENSE

Id: 1/2 Title: Meno (Arduino Compatible)

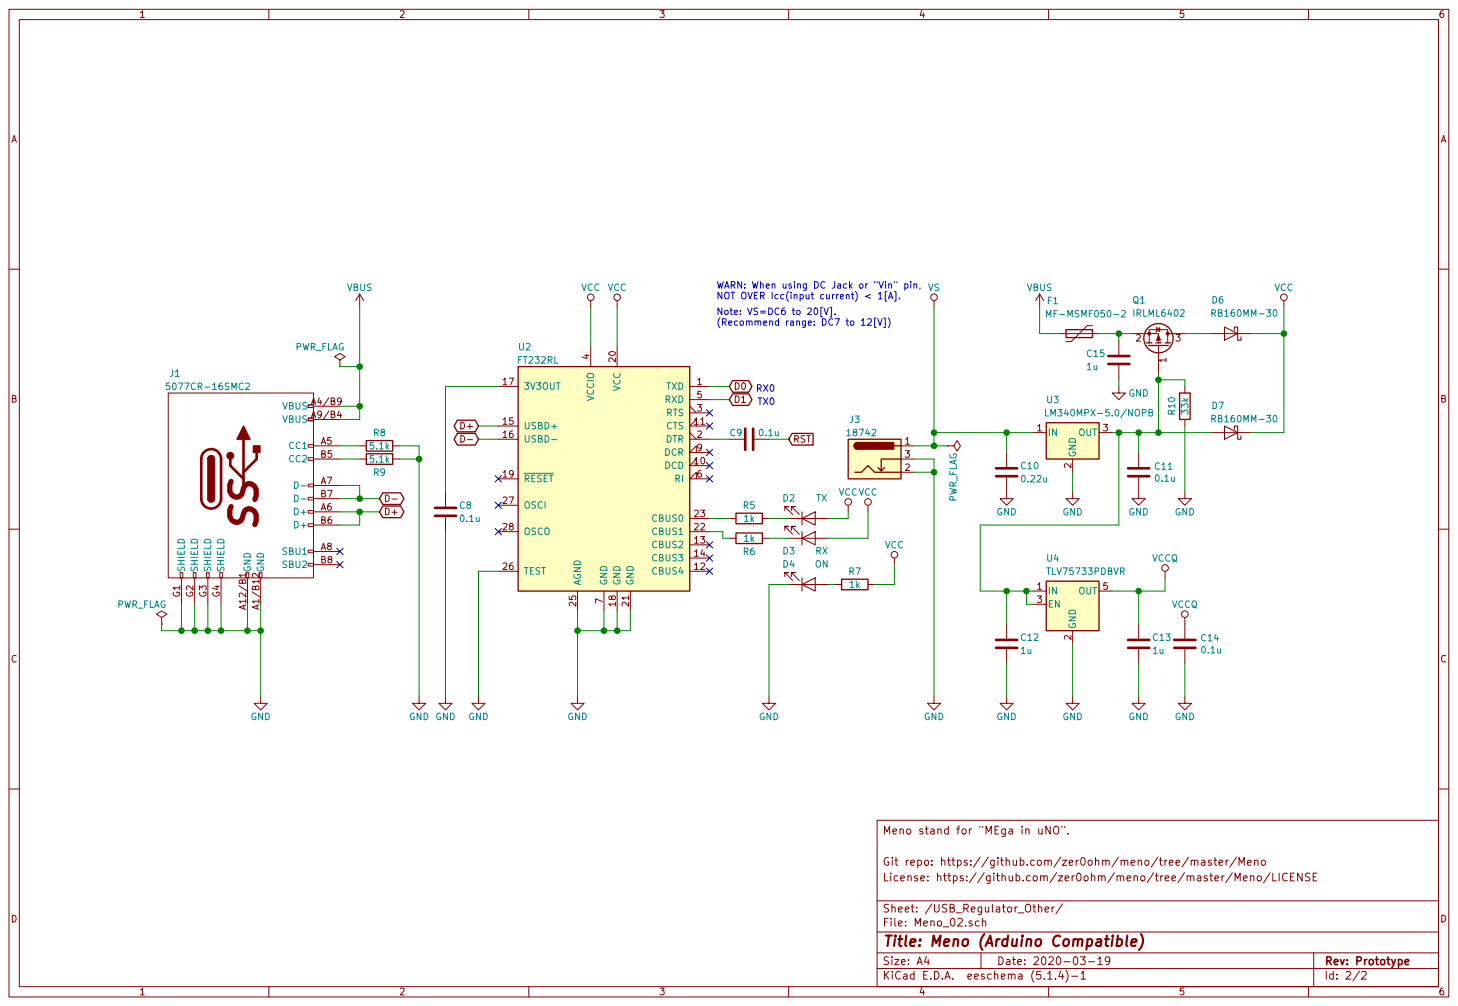
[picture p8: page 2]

TX0 WARN: When using DC Jack or "Vin" pin,
NOT OVER Icc(input current) < 1[A]. RX0 Note: VS=DC6 to 20[V].

Git repo: https://github.com/zer0ohm/meno/tree/master/Meno
License: https://github.com/zer0ohm/meno/tree/master/Meno/LICENSE

Sheet: /USB_Regulator_Other/
File: Meno_02.sch
Id: 2/2 Title: Meno (Arduino Compatible)

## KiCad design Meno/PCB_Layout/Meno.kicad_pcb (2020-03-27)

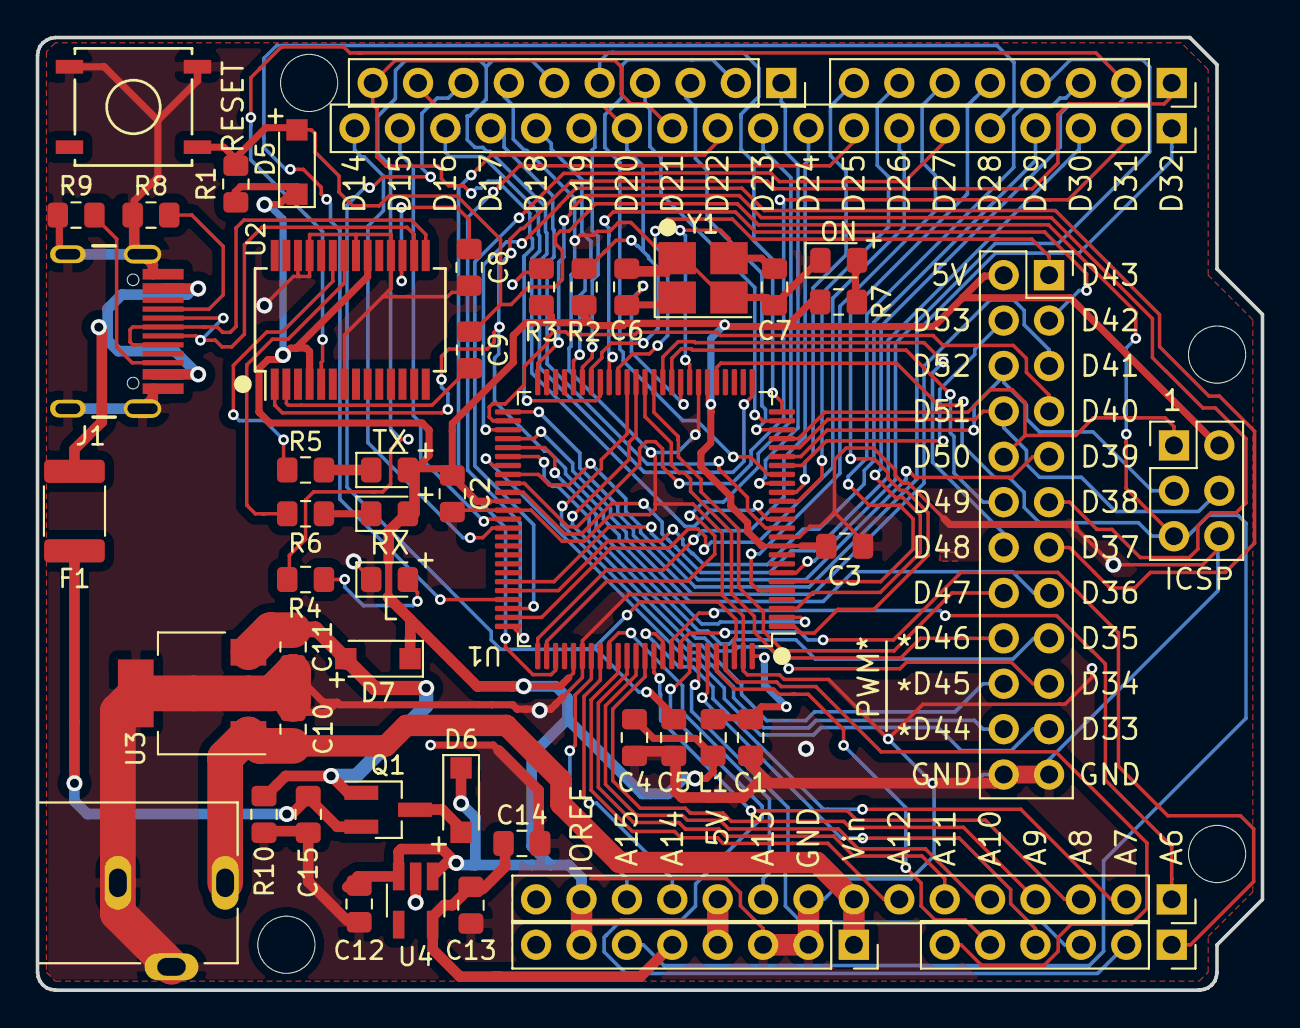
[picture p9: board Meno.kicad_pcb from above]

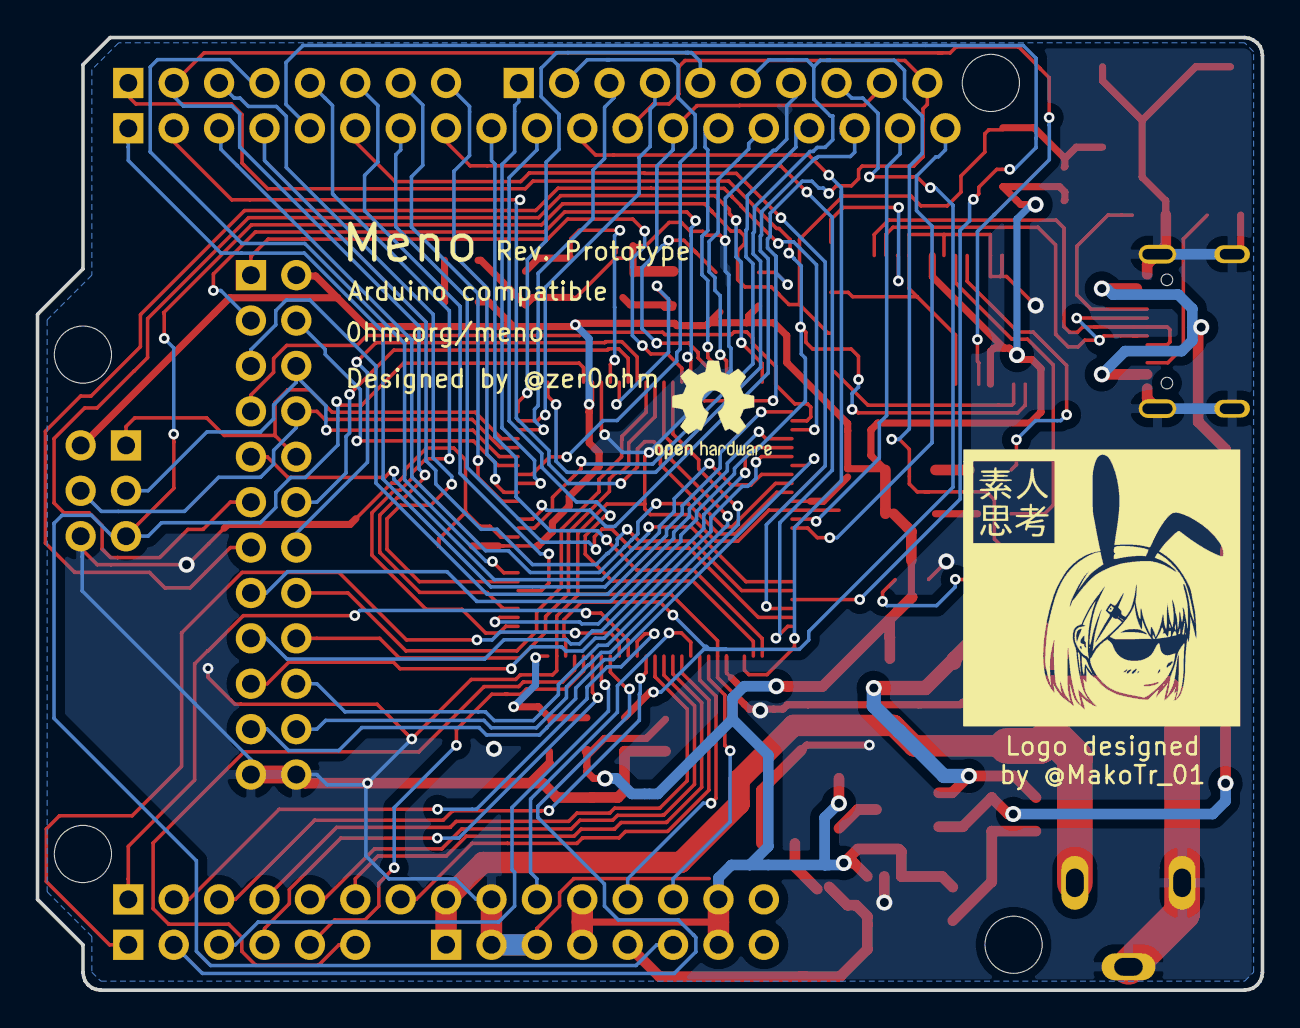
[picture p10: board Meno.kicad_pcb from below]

Board: 2 copper layers, 68.5 x 53.3 mm, 57 parts (2 on the bottom side), 95 nets.

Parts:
C1, C2, C3, C4, C5, C8, C9, C11, C14: 0.1u; C_0805_2012Metric_Pad1.15x1.40mm_HandSolder
C6, C7: 22p; C_0805_2012Metric_Pad1.15x1.40mm_HandSolder
C10: 10u; C_0805_2012Metric_Pad1.15x1.40mm_HandSolder
C12, C13, C15: 1u; C_0805_2012Metric_Pad1.15x1.40mm_HandSolder
D1: L; LED_0805_2012Metric_Pad1.15x1.40mm_HandSolder
D2: TX; LED_0805_2012Metric_Pad1.15x1.40mm_HandSolder
D3: RX; LED_0805_2012Metric_Pad1.15x1.40mm_HandSolder
D4: ON; LED_0805_2012Metric_Pad1.15x1.40mm_HandSolder
D5: 1N4148W; D_SOD-123
D6, D7: RB160MM-30; D_SOD-123
F1: MF-MSMF050-2; Fuse_1812_4532Metric_Pad1.30x3.40mm_HandSolder
J1: 5077CR-16SMC2; GCT_USB4105-GF-A
J2: AVR-ISP-6; PinHeader_2x03_P2.54mm_Vertical
J3: 18742; CUI_PJ-102AH
J4, J8: Conn_01x08; PinSocket_1x08_P2.54mm_Vertical
J5: Conn_01x10; PinSocket_1x10_P2.54mm_Vertical
J6: Conn_01x19; PinSocket_1x19_P2.54mm_Vertical
J7: Conn_01x06; PinSocket_1x06_P2.54mm_Vertical
J9: Conn_01x15; PinSocket_1x15_P2.54mm_Vertical
J10: Conn_02x12; PinSocket_2x12_P2.54mm_Vertical
L1: MH2029-300Y; L_0805_2012Metric_Pad1.15x1.40mm_HandSolder
MH1, MH2, MH3, MH4: Mount_TH_3.2mm_NoWasher
Q1: IRLML6402; SOT-23_Handsoldering
R1, R2, R3: 10k; R_0805_2012Metric_Pad1.15x1.40mm_HandSolder
R4, R5, R6, R7: 1k; R_0805_2012Metric_Pad1.15x1.40mm_HandSolder
R8, R9: 5.1k; R_0805_2012Metric_Pad1.15x1.40mm_HandSolder
R10: 33k; R_0805_2012Metric_Pad1.15x1.40mm_HandSolder
SW1: B3FS-1050P; B3FS-1012
U1: ATmega2560-16AUR; TQFP-100_14x14mm_P0.5mm
U2: FT232RL; SSOP-28_5.3x10.2mm_P0.65mm
U3: LM340MPX-5.0/NOPB; SOT-223-3_TabPin2
U4: LDLN025M33R; SOT-23-5_HandSoldering
Y1: Crystal_SMD_SeikoEpson_FA238-4Pin_3.2x2.5mm_HandS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; Crystal_SMD_SeikoEpson_FA238-4Pin_3.2x2.5mm_HandSoldering
ZLS1: Amateur Intent Logo (Designed by @MakoTr_01); amateur_intent_820dpi
ZLS2: OSHW-Logo2_7.3x6mm_SilkScreen

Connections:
A0: J7.6, U1.97
A1: J7.5, U1.96
A2: J7.4, U1.95
A3: J7.3, U1.94
A4: J7.2, U1.93
A5: J7.1, U1.92
A6: J9.1, U1.91
A7: J9.2, U1.90
A8: J9.3, U1.89
A9: J9.4, U1.88
A10: J9.5, U1.87
A11: J9.6, U1.86
A12: J9.7, U1.85
A13: J9.10, U1.84
A14: J9.12, U1.83
A15: J9.13, U1.82
AREF: C5.1, J5.8, U1.98
D0: J4.1, U1.2, U2.1
D1: J4.2, U1.3, U2.5
D2: J4.3, U1.6
D3: J4.4, U1.7
D4: J4.5, U1.1
D5: J4.6, U1.5
D6: J4.7, U1.15
D7: J4.8, U1.16
D8: J5.1, U1.17
D9: J5.2, U1.18
D10: J5.3, U1.23
D11: J5.4, U1.24
D12: J5.5, U1.25
D13: J5.6, R4.2, U1.26
D14: J6.19, U1.64
D15: J6.18, U1.63
D16: J6.17, U1.13
D17: J6.16, U1.12
D18: J6.15, U1.46
D19: J6.14, U1.45
D20: J5.9, J6.13, R2.1, U1.44
D21: J5.10, J6.12, R3.1, U1.43
D22: J6.11, U1.78
D23: J6.10, U1.77
D24: J6.9, U1.76
D25: J6.8, U1.75
D26: J6.7, U1.74
D27: J6.6, U1.73
D28: J6.5, U1.72
D29: J6.4, U1.71
D30: J6.3, U1.60
D31: J6.2, U1.59
D32: J6.1, U1.58
D33: J10.21, U1.57
D34: J10.19, U1.56
D35: J10.17, U1.55
D36: J10.15, U1.54
D37: J10.13, U1.53
D38: J10.11, U1.50
D39: J10.9, U1.70
D40: J10.7, U1.52
D41: J10.5, U1.51
D42: J10.3, U1.42
D43: J10.1, U1.41
D44: J10.22, U1.40
D45: J10.20, U1.39
D46: J10.18, U1.38
D47: J10.16, U1.37
D48: J10.14, U1.36
D49: J10.12, U1.35
D50: J2.1, J10.10, U1.22
D51: J2.4, J10.8, U1.21
D52: J2.3, J10.6, U1.20
D53: J10.4, U1.19
D+: J1.A6, J1.B6, U2.15
D-: J1.A7, J1.B7, U2.16
GND: C1.2, C2.2, C3.2, C4.2, C5.2, C6.1, C7.1, C8.2, C10.2, C11.2, C12.2, C13.2, C14.2, C15.2, D1.1, D4.1, J1.A1/B12, J1.B1/A12, J1.G1, J1.G2, J1.G3, J1.G4, J2.6, J3.2, J3.3, J5.7, J8.2, J8.3, J9.9, J10.23, J10.24, R8.1, R9.1, R10.2, SW1.1, SW1.2, U1.11, U1.32, U1.62, U1.81, U1.99, U2.7, U2.18, U2.21, U2.25, U2.26, U3.2, U4.2, Y1.2, Y1.4
unnamed: C1.1, L1.1, U1.100
unnamed: C6.2, U1.34, Y1.1
unnamed: C7.2, U1.33, Y1.3
unnamed: C8.1, U2.17
unnamed: C9.2, U2.2
unnamed: C11.1, D7.2, Q1.1, R10.1, U3.3
unnamed: C15.1, F1.1, Q1.2
unnamed: D1.2, R4.1
unnamed: D2.1, R5.1
unnamed: D3.1, R6.1
unnamed: D4.2, R7.1
unnamed: D6.2, Q1.3
unnamed: J1.A5, R8.2
unnamed: J1.B5, R9.2
unnamed: R5.2, U2.23
unnamed: R6.2, U2.22
RST: C9.1, D5.2, J2.5, J8.6, R1.2, SW1.4, U1.30
VBUS: F1.2, J1.A4/B9, J1.B4/A9
VCC: C2.1, C3.1, C4.1, C12.1, D2.2, D3.2, D5.1, D6.1, D7.1, J2.2, J8.4, J8.7, J9.11, J9.14, J10.2, L1.2, R1.1, R2.2, R3.2, R7.2, U1.10, U1.31, U1.61, U1.80, U2.4, U2.20, U4.1, U4.3
VCCQ: C13.1, C14.1, J8.5, U4.5
VS: C10.1, J3.1, J8.1, J9.8, U3.1

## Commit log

2020-03-17 回路図データを追加
    [Meno_01.sch, Meno_02.sch]
2020-03-17 CCライセンスのファイルを追加
2020-03-17 部品表等を追加
    [Meno_BOM.xlsx]
2020-03-17 回路図内のURLを修正
    [Meno_01.sch, Meno_02.sch]
2020-03-17 README内にURLを追加
2020-03-18 BOMのバージョン名を修正
    [Meno_BOM.xlsx]
2020-03-18 ルートリポジトリのREADMEを更新
2020-03-19 基板の設計データを追加
    [Meno.kicad_pcb]
2020-03-19 基板のガーバーデータを追加
    [Meno.gbl, Meno.gbo, Meno.gbs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]
2020-03-19 メタルマスクのガーバーデータを追加
    [Meno.gtp]
2020-03-19 URLを修正
    [Meno_01.sch, Meno_02.sch]
2020-03-19 部品表のフットプリントを修正
    [Meno_BOM.xlsx]
2020-03-20 ピンヘッダ/ソケットの位置を修正
    [Meno.kicad_pcb]
2020-03-20 シルクを修正
    [Meno.kicad_pcb]
2020-03-20 cad32c7での修正に合わせてガーバーデータを更新
    [Meno.gbl, Meno.gbo, Meno.gbs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]
2020-03-23 インデントを修正
2020-03-27 ピンソケットの構成を変更
    [Meno_01.sch, Meno_02.sch]
2020-03-27 0ecd643での変更を基板データに反映
    [Meno.kicad_pcb]
2020-03-27 add6f1aで反映したデータをガーバー化
    [Meno.gbl, Meno.gbo, Meno.gbs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]
2020-03-27 0ecd643での変更を部品表に反映
    [Meno_BOM.xlsx]
2020-03-27 ピン配置図を更新

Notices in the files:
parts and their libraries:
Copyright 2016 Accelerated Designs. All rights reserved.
